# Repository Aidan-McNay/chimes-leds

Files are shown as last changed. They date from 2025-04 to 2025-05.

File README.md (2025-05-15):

# chimes-leds
A system for controlling McGraw Tower's clock face LEDs

## Documentation

Documentation for our system is located [here](https://aidan-mcnay.github.io/chimes-leds/)

Our documentation is built using Sphinx, and is
formatted as [reStructured Text](https://www.sphinx-doc.org/en/master/usage/restructuredtext/basics.html).
To build the documentation locally, first install Sphinx,
as well as our additional Sphinx modules:

```bash
pip install sphinx sphinx_rtd_theme sphinxcontrib-youtube
```

Then, you can build the output files in a `build`
directory with Sphinx, with the top-level HTML
located at `build/index.html`

```bash
sphinx-build docs build
```

This process is automated to update the Github page
on a push

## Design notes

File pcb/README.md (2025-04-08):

# pcb

A collection of the PCB files for:

 - The control panel
 - The sensor board
 - A clock face board

All of these were created with KiCad

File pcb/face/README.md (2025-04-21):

# face

The PCB files for the control board at the playing stand level

## GPIO Mapping

**LED PWM GPIOs (high for on)**:
 - **28**: Red LED
 - **26**: Green LED
 - **20**: Blue LED
 - **18**: White LED

**Status LEDs**:
 - **21**: "On" LED (high when enabled)
 - **19**: Communication LED (On when connected to control panel)

**CAN connections**:
 - **16**: CAN TX
 - **17**: CAN RX
 - **22**: CAN Enable (active low)

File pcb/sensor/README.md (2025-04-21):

# sensor

The PCB files for the control board at the playing stand level

## GPIO Mapping

**Microphone**:
 - **26**: Microphone ADC input

**Ambient Light**:
 - **21**: SCL
 - **20**: SDA
 - **19**: Interrupt (if desired)

**CAN connections**:
 - **16**: CAN TX
 - **17**: CAN RX
 - **22**: CAN Enable (active low)

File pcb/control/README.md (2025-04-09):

# control

The PCB files for the control board at the playing stand level

## GPIO Mapping

**System Configuration**:
 - **4**: System enable (whether to be on)
 - **5**: WiFi enable (whether to use WiFi configs)

**User Mode**:
 - **7**: "Light" mode (based on ambient light, set as pull-down)
 - **8**: "Music" mode (pulse with music, set as pull-down)
 - **9**: "On" mode (always on, set as pull-down)

**Color Potentiometer Inputs**
 - **28**: Red Potentiometer
 - **27**: Green Potentiometer
 - **26**: Blue Potentiometer

**Status LEDs**:
 - **10**: "On" LED (high when enabled)
 - **11**: Red LED (PWM for current color)
 - **12**: Green LED (PWM for current color)
 - **14**: Blue LED (PWM for current color)
 - **15**: WiFi LED (indicate where configs are from)

**Communication LEDs** *(whether we're communicating with a board)*:
 - **3**: Sensor Board
 - **21**: North Face
 - **20**: South Face
 - **19**: East Face
 - **18**: West Face

**CAN connections**:
 - **16**: CAN TX
 - **17**: CAN RX
 - **22**: CAN Enable (active low)

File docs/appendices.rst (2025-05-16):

Appendices
==========================================================================

Appendix A: Permissions
--------------------------------------------------------------------------

* The group approves this report for inclusion on the course website.
* The group approves the video for inclusion on the course YouTube channel.

Appendix B: Source Files
--------------------------------------------------------------------------

An up-to-date listing of our source files can always be found on the
group's `public repository <https://github.com/Aidan-McNay/chimes-leds>`_.
The most recent commit of the repository is additionally included as a
ZIP file below for completeness:

:download:`Download Source Files <files/sources.zip>`

Appendix C: Hardware Designs
--------------------------------------------------------------------------

The group used `KiCad <https://www.kicad.org/>`_ for their PCB design,
with external component symbols/footprints included as necessary from
Digikey's CAD Models (included on the part's page). All of
the design files can be found in the ``pcb`` directory of the source code,
with the schematics of the 3 PCB designs included as PDFs below:

:download:`Control Board Schematic <files/control_schematic.pdf>`

:download:`Sensor Board Schematic <files/sensor_schematic.pdf>`

:download:`Face Board Schematic <files/face_schematic.pdf>`

In addition, a CSV of our Bill of Materials (BOM) can be found here,
with Digikey part numbers and designators on the boards (noting that
the quantities provided are for one face board, but the system uses
four)

:download:`Bill of Materials <files/bom.csv>`

Appendix D: References
--------------------------------------------------------------------------

* Adafruit's wiring guide for their `RGBW LED strip <https://www.adafruit.com/product/2439>`_
  (visually very similar to ours) was used for additional confirmation that
  our understanding of the strips was correct (along with our own testing).
* While all part datasheets were used, the
  `CAN transceiver datasheet <https://www.ti.com/lit/ds/symlink/sn65hvd230.pdf>`_
  in particular proved invaluable by providing different considerations for
  CAN bus implementations, as well as an optimized example layout which
  was followed for all boards.

Appendix E: Member Responsibilities
--------------------------------------------------------------------------

* **Aidan**:

  * CMake build system setup
  * Complete hardware/PCB design, bringup, and debugging
  * Small help with utility class implementations

* **Qingmiao**:

  * Implement CAN bus working on one Pico and one CAN transceiver
  * Small help with utility class implementations

* **Edmund**:

  * Implement software interfaces to the various hardware peripherals,
    including LEDs, potentiometers, and LED-driving MOSFETs
  * Implement the top-level programs for all boards
  * Implement the CAN packet protocol to communicate across boards,
    as well as debug CAN issues

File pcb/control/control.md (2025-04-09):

# control

The PCB files for the control board at the playing stand level

## GPIO Mapping

 - **4**: System Enable
 - **4**: WiFi Enable
 - **7**: "Light" mode (set as pull-down)
 - **8**: "Music" mode (set as pull-down)
 - **9**: "On" mode (set as pull-down)
 - **10**: "On" LED (on when powered)
 - **11**: Red LED (PWM for current color)
 - **12**: Green LED (PWM for current color)
 - **14**: Blue LED (PWM for current color)
 - **15**: WiFi LED (indicate where configs are from)
 - **16**: CAN TX
 - **17**: CAN RX
 - **22**: CAN Enable (active low)
 - **26**: Red Potentiometer
 - **27**: Green Potentiometer
 - **28**: Blue Potentiometer

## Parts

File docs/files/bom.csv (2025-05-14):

Board | Designator | Quantity | Component | Manufacturer ID | Digikey Number
Control | C1 | 1 | 4.7uF | CL10A475KP8NNNC | 1276-1044-1-ND
Control | C2 | 1 | 10uF | CL10A106KQ8NNNC | 1276-1038-1-ND
Control | C3 | 1 | 100nF | CC0603KRX7R7BB104 | 311-1088-1-ND
Control | CR1 | 1 | PESD1CAN_215 | PESD1CANVL | 1727-PESD1CANVLCT-ND
Control | D1,D2,D3,D6,D7,D8,D9,D10 | 8 | LED (R) | XZCM2CRK53WA-8VF | 1497-XZCM2CRK53WA-8VFCT-ND
Control | D4 | 1 | LED (G) | XZCDGK53W-8VF | 1497-XZCDGK53W-8VFCT-ND
Control | D5 | 1 | LED (B) | XZCFBB53W-8VF | 1497-XZCFBB53W-8VFCT-ND
Control | J1 | 1 | Barrel Jack | PJ-102AH | CP-102AH-ND
Control | J2 | 1 | Screw Terminal (1x10) | 1729092 | 277-1244-ND
Control | R1,R2 | 2 | 60Ω | CRCW120660R0KNEAIF | 541-CRCW120660R0KNEAIFCT-ND
Control | R3 | 1 | 10KΩ | RES 10K OHM 1% 1/10W 0603 | 311-10.0KHRCT-ND
Control | R4 | 1 | 100KΩ | ERJ-3EKF1003V | P100KHCT-ND
Control | R5,R6,R7 | 3 | PTA4543 | PTA4543-2015DPA103 | PTA4543-2015DPA103-ND
Control | R8,R9,R10,R13,R14,R15,R16,R17 | 8 | 750Ω | RMCF1206JT750R | RMCF1206JT750RCT-ND
Control | R11,R12 | 2 | 325Ω | ERA-3AEB331V | P330DBCT-ND
Control | S1 | 1 | Rotary Switch | RM103772BCB | CKN10697-ND
Control | SW1,SW2 | 2 | Slide Switch | OS102011MS2QN1 | CKN9565-ND
Control | U1 | 1 | PicoW | SC0918 | 2648-SC0918CT-ND
Control | U2 | 1 | SN65HVD230DR | SN65HVD230DR | 296-11654-1-ND
Control | U3 | 1 | FDN340P | FDN340P | 4518-FDN340PCT-ND
Control | U4 | 1 | DMG2305UX-7 | DMG2305UX-7 | DMG2305UX-7DICT-ND
Face | C1 | 1 | 4.7uF | CL10A475KP8NNNC | 1276-1044-1-ND
Face | C2 | 1 | 10uF | CL10A106KQ8NNNC | 1276-1038-1-ND
Face | C3 | 1 | 100nF | CC0603KRX7R7BB104 | 311-1088-1-ND
Face | C4,C5 | 2 | 4.7uF | CL10A475KP8NNNC | 1276-1044-1-ND
Face | CR1 | 1 | PESD1CAN_215 | PESD1CANVL | 1727-PESD1CANVLCT-ND
Face | D1,D2 | 2 | LED (THT) | 151051RS11000 | 732-5016-ND
Face | J1 | 1 | Screw Terminal (1x2) | 1935161 | 277-1667-ND
Face | J2,J3 | 2 | Screw Terminal (1x5) | 1935190 | 277-1580-ND
Face | J4 | 1 | Big Screw Terminal (1x2) | 282856-2 | A98355-ND
Face | Q1,Q2,Q5,Q6 | 4 | Beefy NFet | IRLB8721PBF | IRLB8721PBF-ND
Face | R1,R2 | 2 | 60Ω | CRCW120660R0KNEAIF | 541-CRCW120660R0KNEAIFCT-ND
Face | R3 | 1 | 100KΩ | ERJ-3EKF1003V | P100KHCT-ND
Face | R4 | 1 | 10KΩ | RES 10K OHM 1% 1/10W 0603 | 311-10.0KHRCT-ND
Face | R5,R6 | 2 | 240Ω | ERJ-3EKF2400V | P240HCT-ND
Face | U1 | 1 | SN65HVD230DR | SN65HVD230DR | 296-11654-1-ND
Face | U2 | 1 | PicoW | SC0918 | 2648-SC0918CT-ND
Face | U3 | 1 | FDN340P | FDN340P | 4518-FDN340PCT-ND
Face | U5 | 1 | DMG2305UX-7 | DMG2305UX-7 | DMG2305UX-7DICT-ND
Face | U6 | 1 | 5V Converter | NCP1117ST50T3G | NCP1117ST50T3GOSCT-ND
Sensor | C1 | 1 | 4.7uF | CL10A475KP8NNNC | 1276-1044-1-ND
Sensor | C2 | 1 | 10uF | CL10A106KQ8NNNC | 1276-1038-1-ND
Sensor | C3 | 1 | 100nF | CC0603KRX7R7BB104 | 311-1088-1-ND
Sensor | CR1 | 1 | PESD1CAN_215 | PESD1CANVL | 1727-PESD1CANVLCT-ND
Sensor | J1 | 1 | 3-pin female header (microphone) | PPTC031LFBN-RC | S7001-ND
Sensor | J2 | 1 | Barrel Jack | PJ-102AH | CP-102AH-ND
Sensor | J3 | 1 | Screw Terminal (1x2) | 1935161 | 277-1667-ND
Sensor | R1,R2 | 2 | 60Ω | CRCW120660R0KNEAIF | 541-CRCW120660R0KNEAIFCT-ND
Sensor | R3 | 1 | 100KΩ | ERJ-3EKF1003V | P100KHCT-ND
Sensor | R4,R7 | 2 | 10KΩ | RES 10K OHM 1% 1/10W 0603 | 311-10.0KHRCT-ND
Sensor | R5,R6 | 2 | 4.7KΩ | RC0603FR-074K7L | 311-4.70KHRCT-ND
Sensor | U1 | 1 | SN65HVD230DR | SN65HVD230DR | 296-11654-1-ND
Sensor | U2 | 1 | FDN340P | FDN340P | 4518-FDN340PCT-ND
Sensor | U3 | 1 | PicoW | SC0918 | 2648-SC0918CT-ND
Sensor | U4 | 1 | Ambient Light | VEML6030-GS15 | VEML6030-GS15CT-ND
Sensor | U5 | 1 | DMG2305UX-7 | DMG2305UX-7 | DMG2305UX-7DICT-ND

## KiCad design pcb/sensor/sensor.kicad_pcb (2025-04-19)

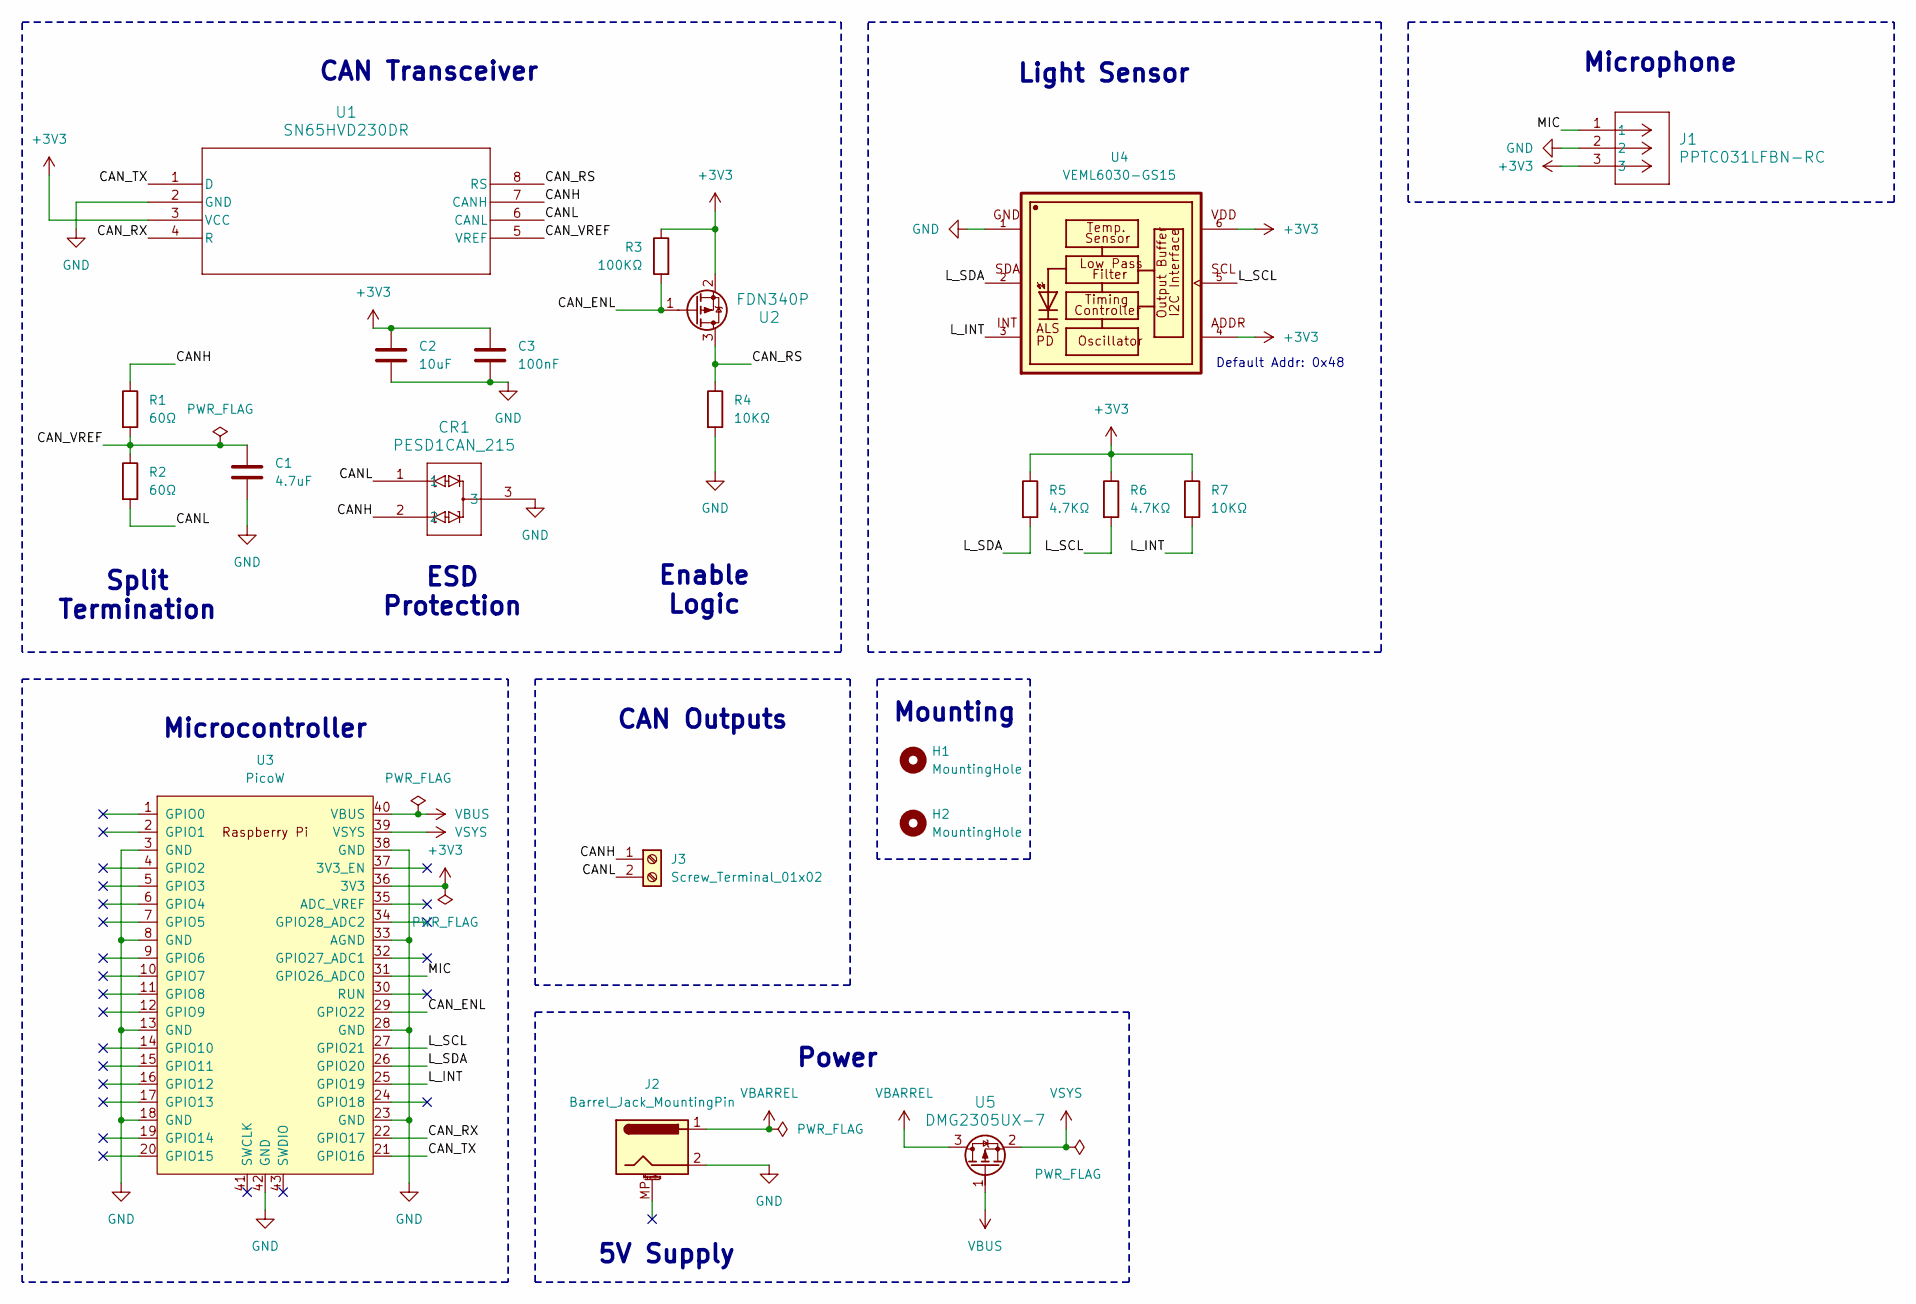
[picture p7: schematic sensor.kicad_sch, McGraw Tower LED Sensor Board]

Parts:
C1: 4.7uF; C_0603_1608Metric
C2: 10uF; C_0603_1608Metric
C3: 100nF; C_0603_1608Metric
CR1: PESD1CAN_215; SOT23_PESD1_NEX
H1, H2: MountingHole; MountingHole_3.2mm_M3_DIN965_Pad
J1: PPTC031LFBN-RC; CONN_PPTC031_SUL
J2: Barrel_Jack_MountingPin; BarrelJack_CUI_PJ-102AH_Horizontal
J3: Screw_Terminal_01x02; TerminalBlock_Phoenix_PT-1,5-2-5.0-H_1x02_P5.00mm_Horizontal
R1, R2: 60Ω; R_1206_3216Metric
R3: 100KΩ; R_0603_1608Metric
R4, R7: 10KΩ; R_0603_1608Metric
R5, R6: 4.7KΩ; R_0603_1608Metric
U1: SN65HVD230DR; D8
U2: FDN340P; SOT-23_ONS
U3: PicoW; RPi_PicoW_SMD_TH
U4: VEML6030-GS15; VISHAY_VEML6030_2X2X0.87
U5: DMG2305UX-7; SOT-23_DIO

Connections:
+3V3: C2.1, C3.1, J1.3, R3.1, R5.1, R6.1, R7.1, U1.3 (VCC), U2.2, U3.36 (3V3), U4.4, U4.6
/CANH: CR1.2, J3.1, R1.1, U1.7 (CANH)
/CANL: CR1.1, J3.2, R2.2, U1.6 (CANL)
/CAN_ENL: R3.2, U2.1, U3.29 (GPIO22)
/CAN_RS: R4.1, U1.8 (RS), U2.3
/CAN_RX: U1.4 (R), U3.22 (GPIO17)
/CAN_TX: U1.1 (D), U3.21 (GPIO16)
/CAN_VREF: C1.1, R1.2, R2.1, U1.5 (VREF)
/L_INT: R7.2, U3.25 (GPIO19), U4.3
/L_SCL: R6.2, U3.27 (GPIO21), U4.5
/L_SDA: R5.2, U3.26 (GPIO20), U4.2
/MIC: J1.1, U3.31 (GPIO26_ADC0)
GND: C1.2, C2.2, C3.2, CR1.3, J1.2, J2.2, R4.2, U1.2 (GND), U3.3 (GND), U3.8 (GND), U3.13 (GND), U3.18 (GND), U3.23 (GND), U3.28 (GND), U3.33 (AGND), U3.38 (GND), U3.42 (GND), U4.1
VBARREL: J2.1, U5.3
VBUS: U3.40 (VBUS), U5.1
VSYS: U3.39 (VSYS), U5.2

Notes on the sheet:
Microphone
CAN Outputs
Microcontroller
CAN Transceiver
Enable Logic
Power
5V Supply
Light Sensor
Mounting
ESD Protection
Split Termination
Default Addr: 0x48

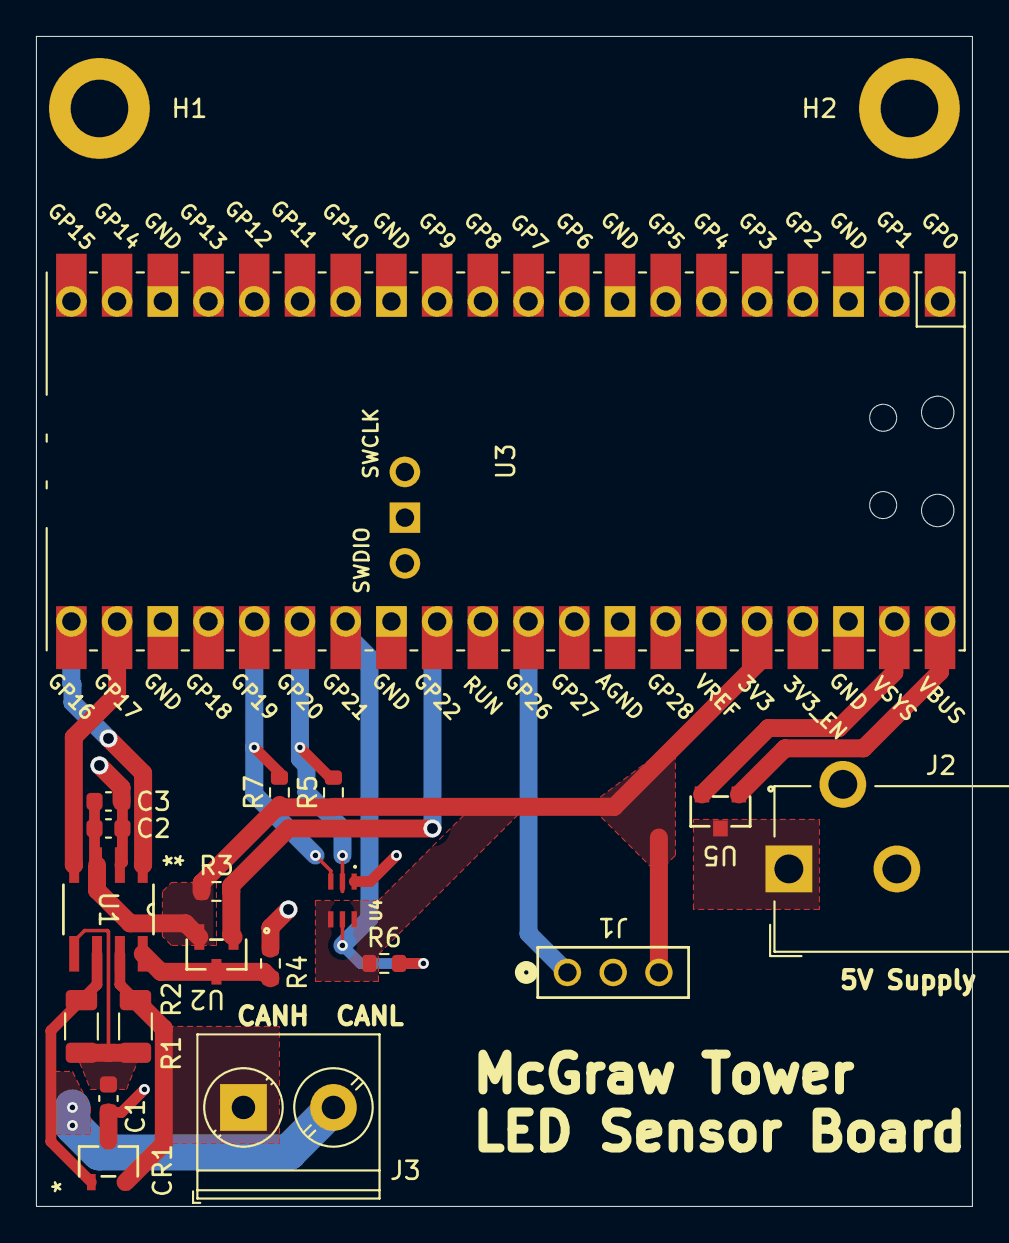
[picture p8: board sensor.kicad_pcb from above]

Board: 2 copper layers, 52.0 x 65.0 mm, 21 parts (0 on the bottom side), 16 nets.

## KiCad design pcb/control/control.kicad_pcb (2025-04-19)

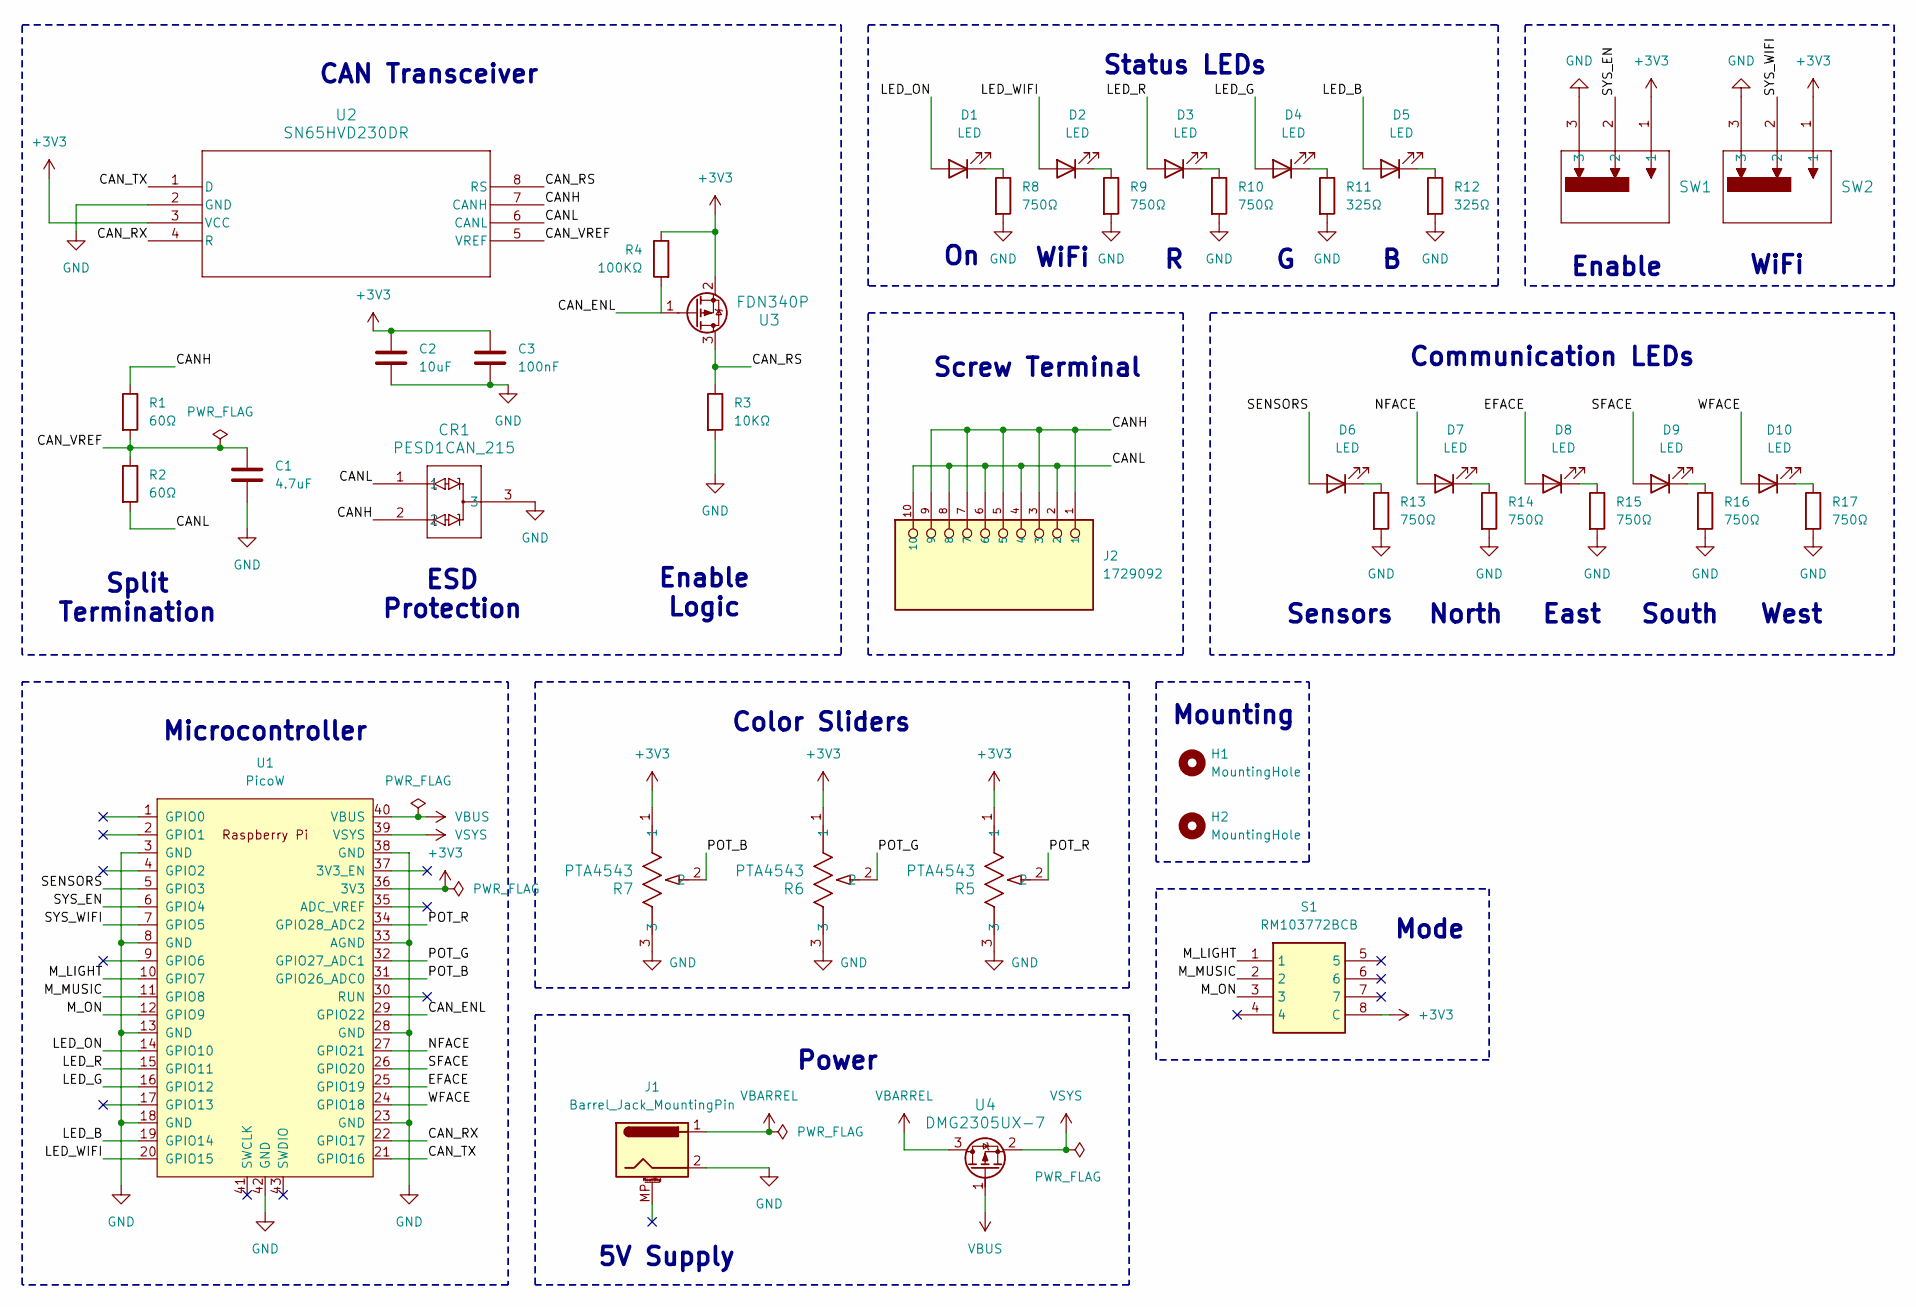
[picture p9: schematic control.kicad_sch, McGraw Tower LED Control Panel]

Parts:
C1: 4.7uF; C_0603_1608Metric
C2: 10uF; C_0603_1608Metric
C3: 100nF; C_0603_1608Metric
CR1: PESD1CAN_215; SOT23_PESD1_NEX
D1, D2, D3, D4, D5, D6, D7, D8, D9, D10: LED; LED_0603_1608Metric
H1, H2: MountingHole; MountingHole_3.2mm_M3_DIN965_Pad
J1: Barrel_Jack_MountingPin; BarrelJack_CUI_PJ-102AH_Horizontal
J2: 1729092; PHOENIX_1729092; DigiKey_Part_Number 277-1244-ND
R1, R2: 60Ω; R_1206_3216Metric
R3: 10KΩ; R_0603_1608Metric
R4: 100KΩ; R_0603_1608Metric
R5, R6, R7: PTA4543; POT_PTA4543
R8, R9, R10, R13, R14, R15, R16, R17: 750Ω; R_1206_3216Metric
R11, R12: 325Ω; R_0603_1608Metric
S1: RM103772BCB; Mouser Part Number 611-RM103772BCB
SW1, SW2: OS102011MS2QN1; SPDT_OS102011_CNK
U1: PicoW; RPi_PicoW_SMD_TH
U2: SN65HVD230DR; D8
U3: FDN340P; SOT-23_ONS
U4: DMG2305UX-7; SOT-23_DIO

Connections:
+3V3: C2.1, C3.1, R4.1, R5.1, R6.1, R7.1, S1.8 (C), SW1.1, SW2.1, U1.36 (3V3), U2.3 (VCC), U3.2
/CANH: CR1.2, J2.1, J2.3, J2.5, J2.7, J2.9, R1.1, U2.7 (CANH)
/CANL: CR1.1, J2.2, J2.4, J2.6, J2.8, J2.10, R2.2, U2.6 (CANL)
/CAN_ENL: R4.2, U1.29 (GPIO22), U3.1
/CAN_RS: R3.1, U2.8 (RS), U3.3
/CAN_RX: U1.22 (GPIO17), U2.4 (R)
/CAN_TX: U1.21 (GPIO16), U2.1 (D)
/CAN_VREF: C1.1, R1.2, R2.1, U2.5 (VREF)
/EFACE: D8.2 (A), U1.25 (GPIO19)
/LED_B: D5.2 (A), U1.19 (GPIO14)
/LED_G: D4.2 (A), U1.16 (GPIO12)
/LED_ON: D1.2 (A), U1.14 (GPIO10)
/LED_R: D3.2 (A), U1.15 (GPIO11)
/LED_WIFI: D2.2 (A), U1.20 (GPIO15)
/M_LIGHT: S1.1, U1.10 (GPIO7)
/M_MUSIC: S1.2, U1.11 (GPIO8)
/M_ON: S1.3, U1.12 (GPIO9)
/NFACE: D7.2 (A), U1.27 (GPIO21)
/POT_B: R7.2, U1.31 (GPIO26_ADC0)
/POT_G: R6.2, U1.32 (GPIO27_ADC1)
/POT_R: R5.2, U1.34 (GPIO28_ADC2)
/SENSORS: D6.2 (A), U1.5 (GPIO3)
/SFACE: D9.2 (A), U1.26 (GPIO20)
/SYS_EN: SW1.2, U1.6 (GPIO4)
/SYS_WIFI: SW2.2, U1.7 (GPIO5)
/WFACE: D10.2 (A), U1.24 (GPIO18)
GND: C1.2, C2.2, C3.2, CR1.3, J1.2, R3.2, R5.3, R6.3, R7.3, R8.2, R9.2, R10.2, R11.2, R12.2, R13.2, R14.2, R15.2, R16.2, R17.2, SW1.3, SW2.3, U1.3 (GND), U1.8 (GND), U1.13 (GND), U1.18 (GND), U1.23 (GND), U1.28 (GND), U1.33 (AGND), U1.38 (GND), U1.42 (GND), U2.2 (GND)
unnamed: D1.1 (K), R8.1
unnamed: D2.1 (K), R9.1
unnamed: D3.1 (K), R10.1
unnamed: D4.1 (K), R11.1
unnamed: D5.1 (K), R12.1
unnamed: D6.1 (K), R13.1
unnamed: D7.1 (K), R14.1
unnamed: D8.1 (K), R15.1
unnamed: D9.1 (K), R16.1
unnamed: D10.1 (K), R17.1
VBARREL: J1.1, U4.3
VBUS: U1.40 (VBUS), U4.1
VSYS: U1.39 (VSYS), U4.2

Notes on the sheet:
WiFi
Sensors
Status LEDs
5V Supply
Split Termination
Power
Mode
South
Color Sliders
Communication LEDs
Enable Logic
East
Enable
Screw Terminal
Microcontroller
CAN Transceiver
ESD Protection
North
Mounting
West

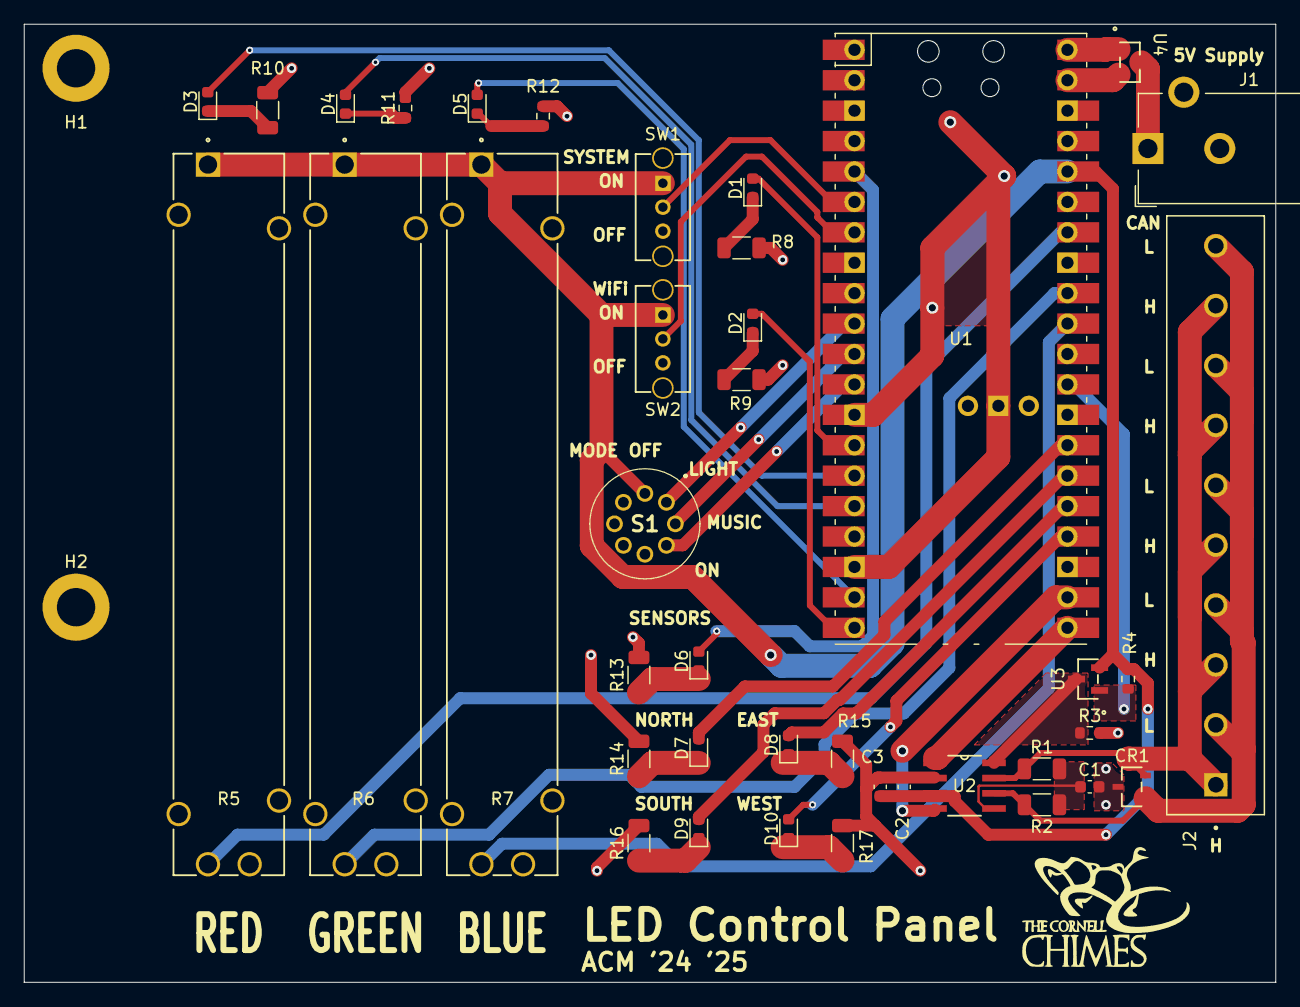
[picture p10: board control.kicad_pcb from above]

Board: 2 copper layers, 104.5 x 80.0 mm, 42 parts (0 on the bottom side), 40 nets.

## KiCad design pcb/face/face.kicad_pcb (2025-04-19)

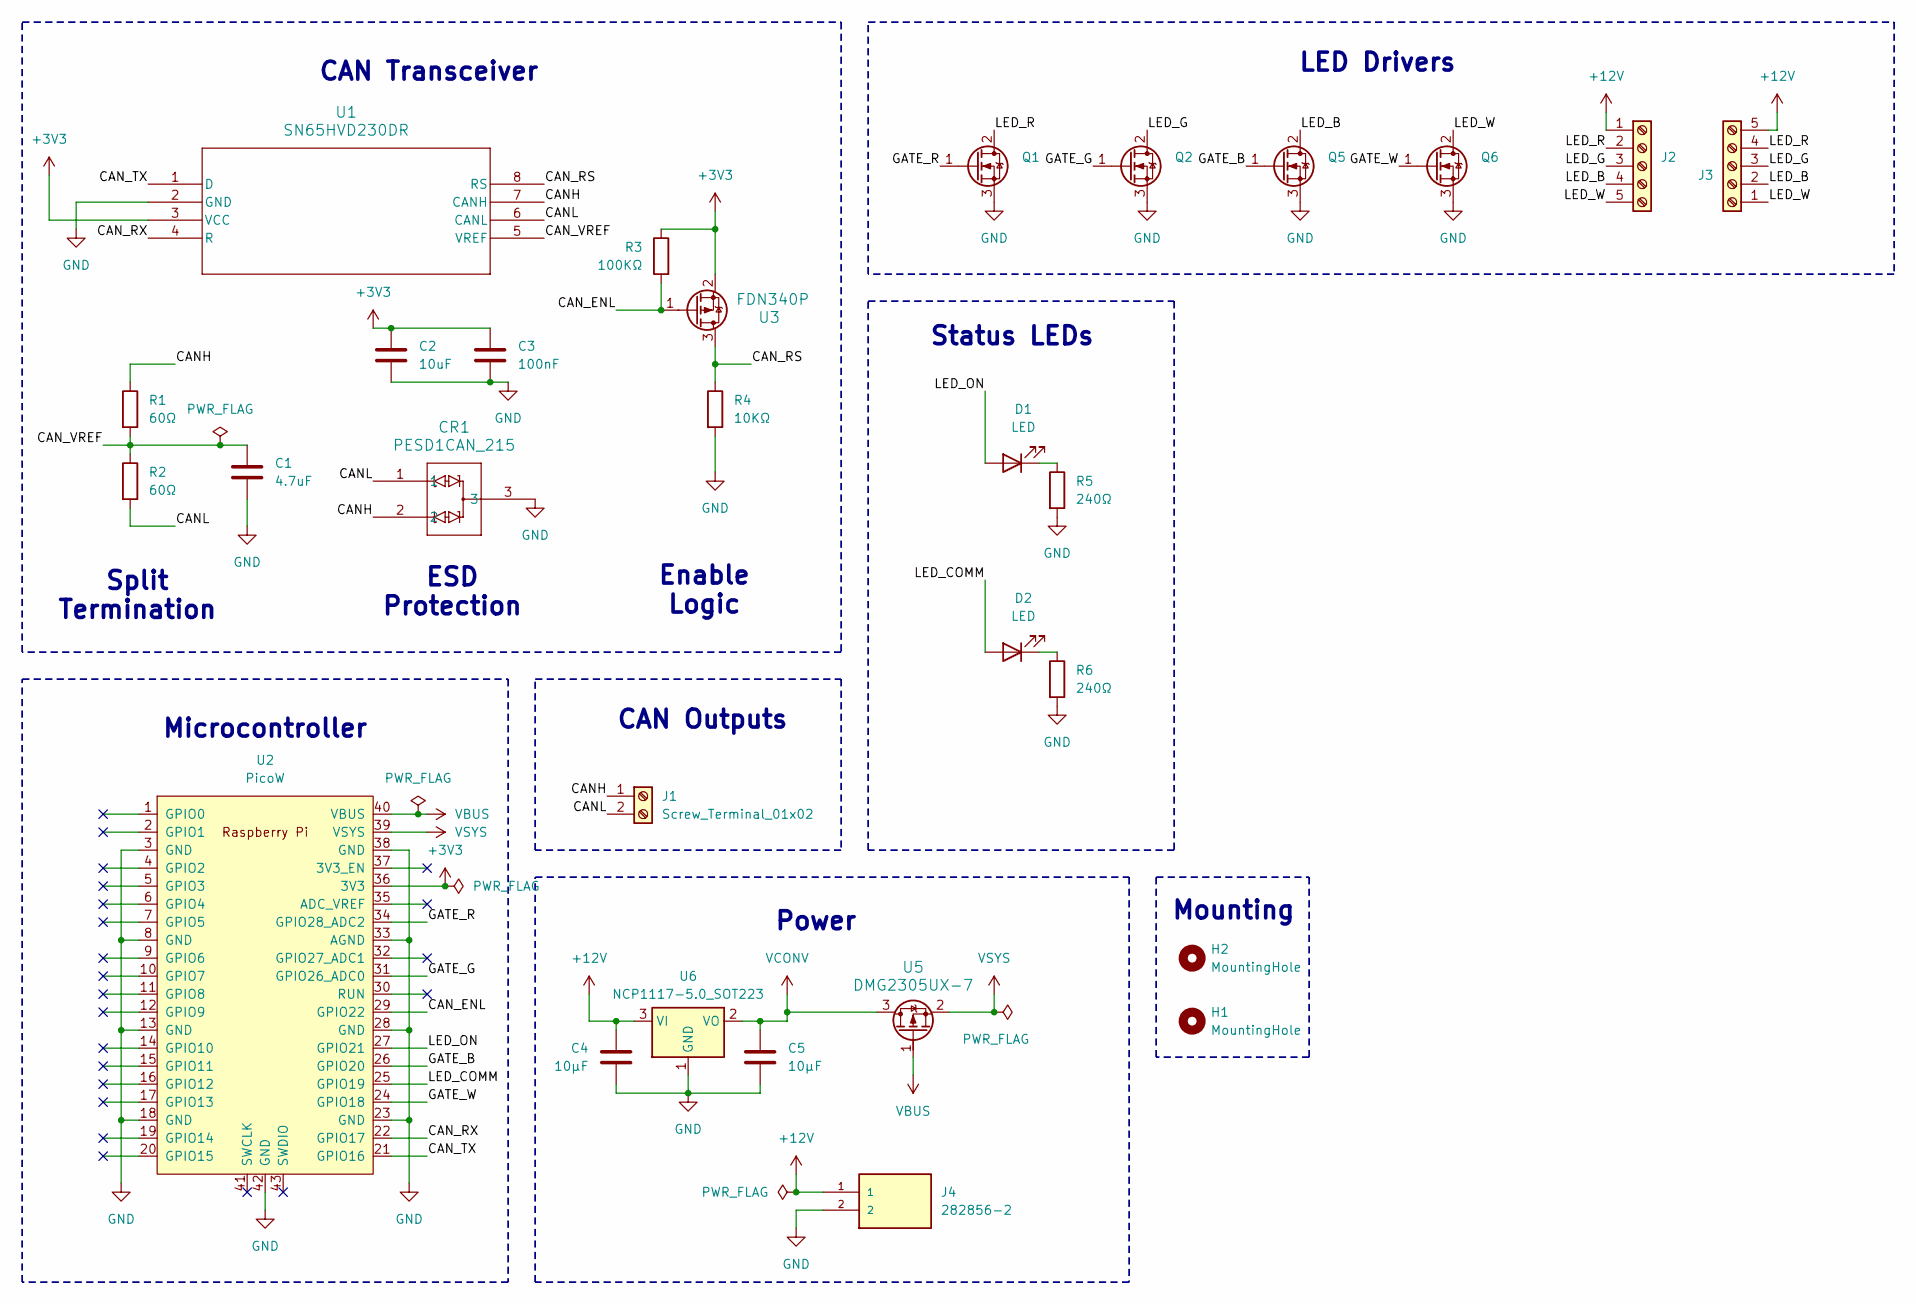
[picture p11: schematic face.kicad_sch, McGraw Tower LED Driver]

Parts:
C1: 4.7uF; C_0603_1608Metric
C2: 10uF; C_0603_1608Metric
C3: 100nF; C_0603_1608Metric
C4, C5: 10μF; C_0603_1608Metric
CR1: PESD1CAN_215; SOT23_PESD1_NEX
D1, D2: LED; LED_D5.0mm
H1, H2: MountingHole; MountingHole_3.2mm_M3_DIN965_Pad
J1: Screw_Terminal_01x02; TerminalBlock_Phoenix_PT-1,5-2-5.0-H_1x02_P5.00mm_Horizontal
J2, J3: Screw_Terminal_01x05; TerminalBlock_Phoenix_PT-1,5-5-5.0-H_1x05_P5.00mm_Horizontal
J4: 282856-2; TE_282856-2; PARTREV R
Q1, Q2, Q5, Q6: IRLB8721PBF; TO-220-3_Vertical
R1, R2: 60Ω; R_1206_3216Metric
R3: 100KΩ; R_0603_1608Metric
R4: 10KΩ; R_0603_1608Metric
R5, R6: 240Ω; R_0603_1608Metric
U1: SN65HVD230DR; D8
U2: PicoW; RPi_PicoW_SMD_TH
U3: FDN340P; SOT-23_ONS
U5: DMG2305UX-7; SOT-23_DIO
U6: NCP1117-5.0_SOT223; SOT-223-3_TabPin2

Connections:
+3V3: C2.1, C3.1, R3.1, U1.3 (VCC), U2.36 (3V3), U3.2
+12V: C4.1, J2.1, J3.5, J4.1, U6.3 (VI)
/CANH: CR1.2, J1.1, R1.1, U1.7 (CANH)
/CANL: CR1.1, J1.2, R2.2, U1.6 (CANL)
/CAN_ENL: R3.2, U2.29 (GPIO22), U3.1
/CAN_RS: R4.1, U1.8 (RS), U3.3
/CAN_RX: U1.4 (R), U2.22 (GPIO17)
/CAN_TX: U1.1 (D), U2.21 (GPIO16)
/CAN_VREF: C1.1, R1.2, R2.1, U1.5 (VREF)
/GATE_B: Q5.1 (G), U2.26 (GPIO20)
/GATE_G: Q2.1 (G), U2.31 (GPIO26_ADC0)
/GATE_R: Q1.1 (G), U2.34 (GPIO28_ADC2)
/GATE_W: Q6.1 (G), U2.24 (GPIO18)
/LED_B: J2.4, J3.2, Q5.2 (D)
/LED_COMM: D2.2 (A), U2.25 (GPIO19)
/LED_G: J2.3, J3.3, Q2.2 (D)
/LED_ON: D1.2 (A), U2.27 (GPIO21)
/LED_R: J2.2, J3.4, Q1.2 (D)
/LED_W: J2.5, J3.1, Q6.2 (D)
GND: C1.2, C2.2, C3.2, C4.2, C5.2, CR1.3, J4.2, Q1.3 (S), Q2.3 (S), Q5.3 (S), Q6.3 (S), R4.2, R5.2, R6.2, U1.2 (GND), U2.3 (GND), U2.8 (GND), U2.13 (GND), U2.18 (GND), U2.23 (GND), U2.28 (GND), U2.33 (AGND), U2.38 (GND), U2.42 (GND), U6.1 (GND)
unnamed: D1.1 (K), R5.1
unnamed: D2.1 (K), R6.1
VBUS: U2.40 (VBUS), U5.1
VCONV: C5.1, U5.3, U6.2 (VO)
VSYS: U2.39 (VSYS), U5.2

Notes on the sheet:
LED Drivers
Status LEDs
Microcontroller
CAN Transceiver
Mounting
CAN Outputs
Enable Logic
Split Termination
ESD Protection
Power

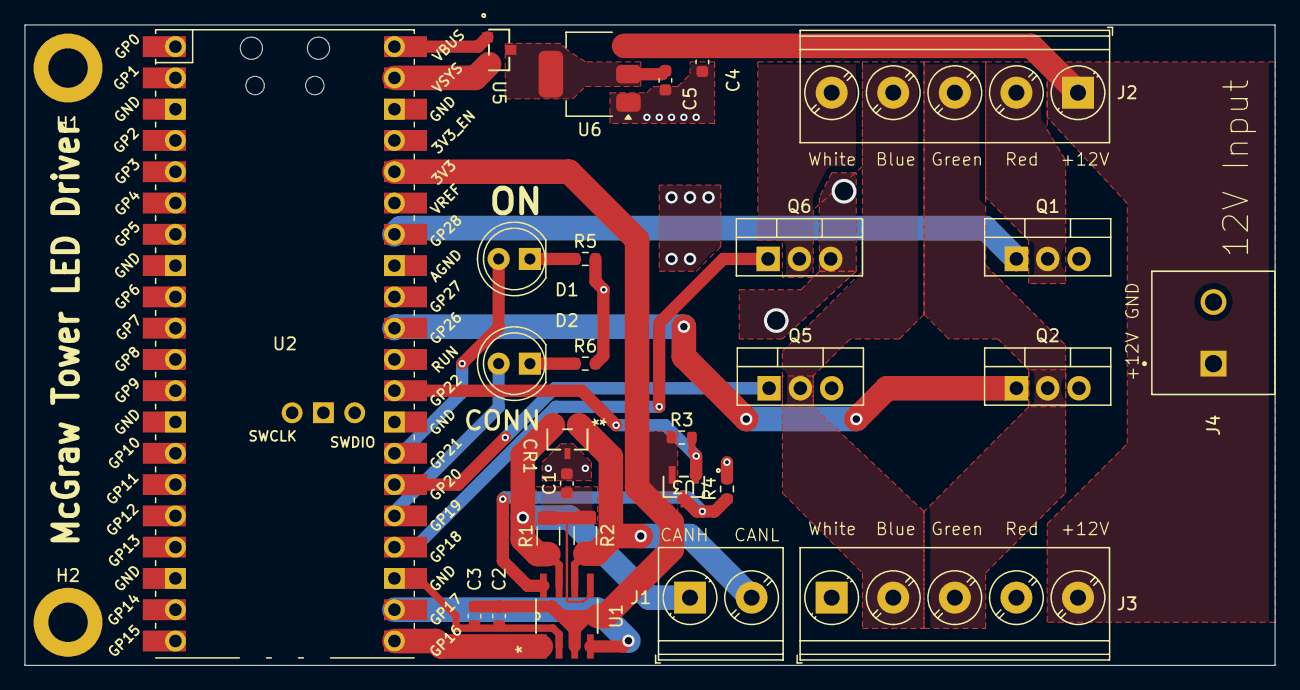
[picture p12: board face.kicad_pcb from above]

Board: 2 copper layers, 101.5 x 52.0 mm, 29 parts (0 on the bottom side), 25 nets.

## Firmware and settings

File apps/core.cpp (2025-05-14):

// Standard C libraries
#include <stdio.h>
#include <string.h>
#include <stdlib.h>
// High-level pico libraries
#include "pico/stdlib.h"
#include "pico/multicore.h"
// Interface library to sys_clock (SDK 2.0.0 )
#include "hardware/clocks.h"
// CAN driver
#include "can/can.h"
// Protothreads
#include "utils/pt_cornell_rp2040_v1.h"
#include "utils/can_interface.h"
#include "utils/state.h"
#include "interface/switch.h"
#include "interface/color_adc.h"
#include "interface/led.h"
#include "interface/pwm.h"
#include "can/can.h"
#include "interface/pico_led.h"
#include "utils/fix15.h"

State core_state = State();

CAN can_bus( CORE_ARBITRATION, NETWORK_BROADCAST, 16, 22);

Switch system_enable(4); // whether to be on
Switch wifi_enable(5);   // whether to use WiFi configs
Switch light_mode(7);
Switch music_mode(8);
Switch on_mode(9);

ColorInput color_in;

LED is_on(10);
PWM red_out(11, 125.0f, 255, 0);
PWM green_out(12, 125.0f, 255, 0);
PWM blue_out(14, 125.0f, 255, 0);
LED wifi_on(15);

void on_color_update(State *s) {
  color_rgb c = s->get_led_color().get_rgb();

  printf("Setting color to %d %d %d\n", c.red, c.green, c.blue);

  red_out.set_duty(c.red);
  green_out.set_duty(c.green);
  blue_out.set_duty(c.blue);

  unsigned short payload[4];

  payload[0] = SET_COLOR;
  payload[1] = c.red;
  payload[2] = c.green;
  payload[3] = c.blue;

  can_bus.set_payload(payload, 4);

  can_bus.set_arbitration(CLOCK_FACE_ARBITRATION[0]);
  can_bus.sendPacket();

  // for (short clock_face : CLOCK_FACE_ARBITRATION) {
  //   can_bus.set_arbitration(clock_face);
  //   can_bus.sendPacket();
  // }
}

void on_led_update(State *s) {
  bool on = s->get_led_on();

  unsigned short payload[2];

  payload[0] = SET_TOGGLE;
  payload[1] = on;
  can_bus.set_payload(payload, 2);

  for (short clock_face : CLOCK_FACE_ARBITRATION) {
    can_bus.set_arbitration(clock_face);
    can_bus.sendPacket();
  }
}

void on_mode_change(State *s) {
      unsigned short payload[1];
  switch (s->get_led_mode()) {
    case LIGHT:
      // Send light mode to light sensor
      payload[0] = SENSOR_LIGHT;
      break;
    case MUSIC:
      // Send music mode to sound sensor
      payload[0] = SENSOR_SOUND;
      break;
    case CONST:
      // Send const mode to clock face
      payload[0] = SET_TOGGLE;
      break;
  }
  
  can_bus.set_payload(payload, 1);
  can_bus.set_arbitration(SENSOR_ARBITRATION);
  can_bus.sendPacket();

  // If the mode is set to const, turn on the LED
  if (s->get_led_mode() == CONST) {
    s->set_led_on(true);
  }

  // Otherwise, this will be handled elsewhere
}

// Read sensor data
fix15 last_light;
fix15 last_sound;

#define DECIBEL_MAX int2fix15(100)
#define DECIBEL_MIN int2fix15(0)

void read_packet( const unsigned short* packet, const unsigned char len ) {
  switch (packet[0]) {
    case SENSOR_LIGHT:
      // Right the light sensor data
      if (len != 3) {
        printf("Error: light packet length %d\n", len);
        return;
      }

      last_light = (packet[1] << 16) + packet[2];
      break;

    case SENSOR_SOUND:
      // Right the sound sensor data
      if (len != 3) {
        printf("Error: sound packet length %d\n", len);
        return;
      }

      last_sound = (packet[1] << 16) + packet[2];
      printf("Received sound data %f\n", fix2float15(last_sound));
      break;
    default:
      // Nothing to do here
      break;
  }
}

// us per sample
#define PARAM_SAMPLE_RATE 10000

// Lux cap for light sensor below which to turn on LEDs
#define LUX_CAP int2fix15(1)

static PT_THREAD( protothread_core( struct pt *pt ) )
{
  PT_BEGIN( pt );
  static int begin_time, elapsed_time;

  while (1) {
    // Measure time at start of thread
    begin_time = time_us_32();
    
    is_on.toggle(system_enable.enabled());
    wifi_on.toggle(wifi_enable.enabled());

    if (system_enable.enabled()) {

      if (light_mode.enabled()) {
        core_state.set_led_mode(LIGHT);
      } else if (music_mode.enabled()) {
        core_state.set_led_mode(MUSIC);
      } else if (on_mode.enabled()) {
        core_state.set_led_mode(CONST);
      } else {
        printf("No modes selected.\n");
      }

      printf("Running in mode %d\n", core_state.get_led_mode());

      color_rgb c = color_in.sample();
      
      switch (core_state.get_led_mode()) {
        case LIGHT:
          // Send light sensor data to watch faces
          if (last_light > LUX_CAP) {
            // Set the color to the light sensor value
            core_state.set_led_on(true);
          } else {
            // Turn off the LEDs
            core_state.set_led_on(false);
          }
          break;
        case MUSIC:
          core_state.set_led_on(true);
          printf("Current volume %f\n", fix2float15(last_sound));

        
          // Set brightness based on volume
          c.red = (uint8_t) ((float) c.red * fix2float15(last_sound));
          c.green = (uint8_t) ((float) c.green * fix2float15(last_sound));
          c.blue = (uint8_t) ((float) c.blue * fix2float15(last_sound));

          break;
        case CONST:
          
          core_state.set_led_on(true);
          // Handle manual mode
          // Read red, green, and blue in values and set the color
          break;
      }
      
      core_state.set_led_color(Color(c));
    } else {
      // If the system is not enabled, turn off the LEDs
      core_state.set_led_on(false);
      printf("System disabled\n");
    }
  

    elapsed_time = time_us_32() - begin_time;

    // yield for necessary amount of time
    PT_YIELD_usec( PARAM_SAMPLE_RATE - elapsed_time );
  }
  PT_END( pt );
}

//                        USER INTERRUPT SERVICE ROUTINES
//
// ISR entered at the end of packet transmit.
void tx_handler() {
  can_bus.handle_tx() ;
}
// ISR entered when a packet is available for attempted receipt.
void rx_handler() {
  can_bus.handle_rx() ;
}

//                             MAIN FOR CORES 0 AND 1
//
// Main for core 1
void core1_main() {
    // CAN transmitter will run on core 1
    can_bus.setupCANTX(tx_handler) ;

    printf("TX handler set up\n");
    
    pt_add_thread( protothread_core );

    // Start the threader
    pt_schedule_start ;
}

// Main for core 0
int main() {
  // Overclock to 160MHz (divides evenly to 1 megabaud) (160/5/32=1)
  set_sys_clock_khz(OVERCLOCK_RATE, true) ;

  // Initialize stdio
  stdio_init_all();
  sleep_ms(5000);

  printf("Launching...\n");

  // Initialize state callbacks
  core_state.add_led_on_callback( on_led_update );
  core_state.add_led_mode_callback( on_mode_change );
  core_state.add_led_color_callback( on_color_update );

  red_out.toggle(true);
  green_out.toggle(true);
  blue_out.toggle(true);

  // start core 1 threads
  multicore_reset_core1();
  multicore_launch_core1(&core1_main);

  // Set can bus callback
  can_bus.set_callback( read_packet );

  // Setup the CAN receiver on core 0
  can_bus.setupCANRX(rx_handler) ;

  printf("RX handler set up\n");

  pt_schedule_start ;
}

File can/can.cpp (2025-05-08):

#include "can.pio.h"
#include "can/can.h"
#include "hardware/dma.h"
#include "hardware/pio.h"
#include "pico/stdlib.h"
#include "stdio.h"
#include <string.h>

// 2344 D506 0820 B041 0608 2082 0824 C106 FFFF

// ----------------------------------------------------------------------
// Define buffers for storing studded/unstuffed packets for TX/RX
// ----------------------------------------------------------------------

// Assembled packet for transmission (unstuffed then stuffed)
unsigned short  tx_packet_unstuffed[MAX_PACKET_LEN]       = { 0 };
unsigned short  tx_packet_stuffed[MAX_STUFFED_PACKET_LEN] = { 0 };
unsigned short* tx_packet_stuffed_pointer = &tx_packet_stuffed[0];

// Buffer for received packets (stuffed then unstuffed)
unsigned short  rx_packet_stuffed[MAX_STUFFED_PACKET_LEN] = { 0 };
unsigned short  rx_packet_unstuffed[MAX_PACKET_LEN]       = { 0 };
// unsigned char* rx_packet_stuffed_pointer = (unsigned char*) (&rx_packet_stuffed[0]);
unsigned short* rx_packet_stuffed_pointer = &rx_packet_stuffed[0];

// For re-initializing these buffers
unsigned short zero_packet[MAX_STUFFED_PACKET_LEN] = { 0 };

// ----------------------------------------------------------------------
// Define infrastructure globals
// ----------------------------------------------------------------------

// PIO blocks
PIO pio_0 = pio0;
PIO pio_1 = pio1;
// State machines
int can_tx_sm         = 0;
int can_idle_check_sm = 1;
int can_rx_sm         = 0;
// Select dma channels
int dma_chan_0 = 5;
int dma_chan_1 = 4;
int dma_chan_2 = 2;
int dma_chan_3 = 3;
// Dummy DMA source/destination for chained channel
unsigned int dummy_source = 0;
unsigned int dummy_dest   = 0;

// ----------------------------------------------------------------------
// Initialize CAN driver
// ----------------------------------------------------------------------

CAN::CAN( unsigned short my_arbitration, unsigned short network_broadcast,
          int can_tx, int transceiver_en
)
    : 
      packet_handler( NULL ),
      can_tx( can_tx ),
      transceiver_en( transceiver_en ),
      my_arbitration( my_arbitration ),
      arbitration( 0 ),
      network_broadcast( network_broadcast ),
      tx_idle_time( 500 ),
      reserve_byte( 0x55 ),
      payload_len( 10 ),
      number_sent( 0 ),
      number_received( 0 ),
      number_missed( 0 ),
      unsafe_to_tx( 1 )
{
}

// ----------------------------------------------------------------------
// Public accessor functions
// ----------------------------------------------------------------------

// ISR entered at the end of packet transmit
void CAN::handle_tx()
{
  // Abort/reset DMA channel, clear FIFO, clear PIO irq
  resetTransmitter();
  number_sent += 1;
  // Signal to thread that it is safe to transmit
  unsafe_to_tx = 0;
}

// ISR entered when a packet is available for attempted receipt
void CAN::handle_rx()
{
  // Abort/reset DMA channel
  resetReceiver();
  // Attempt packet receipt
  if ( attemptPacketReceive() ) {
    number_received += 1;

    // Call the packet handler
    if ( packet_handler ) {
      packet_handler( &rx_packet_unstuffed[2], rx_packet_unstuffed[1] & 0xFF );
    }
  }
  else {
    number_missed += 1;
  }

  // Clear the interrupt to receive the next message
  acceptNewPacket();
}

// Computes the checksum over a series of bytes
unsigned short CAN::culCalcCRC( char crcData, unsigned short crcReg )
{
  for ( int i = 0; i < 8; i++ ) {
    if ( ( ( crcReg & 0x8000 ) >> 8 ) ^ ( crcData & 0x80 ) ) {
      crcReg = ( crcReg << 1 ) ^ CRC16_POLY;
    }
    else {
      crcReg = ( crcReg << 1 );
    }
    crcData <<= 1;
  }
  return crcReg;
}

// Packet transmission
unsigned short CAN::getBitShort( unsigned short* shorty,
                                 unsigned char   bitnum )
{
  switch ( bitnum ) {
    case 0:
      return ( ( *shorty & 0x8000 ) >> 15 );
    case 1:
      return ( ( *shorty & 0x4000 ) >> 14 );
    case 2:
      return ( ( *shorty & 0x2000 ) >> 13 );
    case 3:
      return ( ( *shorty & 0x1000 ) >> 12 );
    case 4:
      return ( ( *shorty & 0x0800 ) >> 11 );
    case 5:
      return ( ( *shorty & 0x0400 ) >> 10 );
    case 6:
      return ( ( *shorty & 0x0200 ) >> 9 );
    case 7:
      return ( ( *shorty & 0x0100 ) >> 8 );
    case 8:
      return ( ( *shorty & 0x0080 ) >> 7 );
    case 9:
      return ( ( *shorty & 0x0040 ) >> 6 );
    case 10:
      return ( ( *shorty & 0x0020 ) >> 5 );
    case 11:
      return ( ( *shorty & 0x0010 ) >> 4 );
    case 12:
      return ( ( *shorty & 0x0008 ) >> 3 );
    case 13:
      return ( ( *shorty & 0x0004 ) >> 2 );
    case 14:
      return ( ( *shorty & 0x0002 ) >> 1 );
    case 15:
      return ( ( *shorty & 0x0001 ) >> 0 );
    default:
      return 0xFFFF;
  }
}

void CAN::modifyBitShort( unsigned short* shorty, unsigned char bitnum,
                          unsigned short value )
{
  switch ( bitnum ) {
    case 15:
      *shorty |= ( ( value << 0 ) & 0x0001 );
      break;
    case 14:
      *shorty |= ( ( value << 1 ) & 0x0002 );
      break;
    case 13:
      *shorty |= ( ( value << 2 ) & 0x0004 );
      break;
    case 12:
      *shorty |= ( ( value << 3 ) & 0x0008 );
      break;
    case 11:
      *shorty |= ( ( value << 4 ) & 0x0010 );
      break;
    case 10:
      *shorty |= ( ( value << 5 ) & 0x0020 );
      break;
    case 9:
      *shorty |= ( ( value << 6 ) & 0x0040 );
      break;
    case 8:
      *shorty |= ( ( value << 7 ) & 0x0080 );
      break;
    case 7:
      *shorty |= ( ( value << 8 ) & 0x0100 );
      break;
    case 6:
      *shorty |= ( ( value << 9 ) & 0x0200 );
      break;
    case 5:
      *shorty |= ( ( value << 10 ) & 0x0400 );
      break;
    case 4:
      *shorty |= ( ( value << 11 ) & 0x0800 );
      break;
    case 3:
      *shorty |= ( ( value << 12 ) & 0x1000 );
      break;
    case 2:
      *shorty |= ( ( value << 13 ) & 0x2000 );
      break;
    case 1:
      *shorty |= ( ( value << 14 ) & 0x4000 );
      break;
    case 0:
      *shorty |= ( ( value << 15 ) & 0x8000 );
      break;
    default:
      printf( "Invalid argument to modifyBitChar   \n" );
      break;
  }
}
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

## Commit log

2025-04-08 Started control PCB
    [control.kicad_pcb, control.kicad_sch]
2025-04-08 Remove KiCad backups
2025-04-09 Working on control PCB more
    [control.kicad_sch]
2025-04-09 Schematic finished, working on layout
    [control.kicad_pcb, control.kicad_sch]
2025-04-09 Update control schematic
    [control.kicad_sch]
2025-04-09 Control PCB done
    [control.kicad_pcb, control.kicad_sch]
2025-04-09 Increase power trace width
    [control.kicad_pcb]
2025-04-10 Started sensor board
    [sensor.kicad_pcb, sensor.kicad_sch]
2025-04-10 Add light sensor
2025-04-14 Worked on PCBs
    [face.kicad_pcb, face.kicad_sch, sensor.kicad_sch]
2025-04-14 Incremental PCB
    [sensor.kicad_sch]
2025-04-18 PCBs hopefully done
    [control.kicad_pcb, control.kicad_sch, face.kicad_pcb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]
2025-04-19 Final boards
    [control.kicad_pcb, control.kicad_sch, face.kicad_pcb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]
2025-04-21 Pin mapping
2025-04-23 working calibration script
2025-04-28 fixed calibration software
2025-05-02 working adc round robin
2025-05-02 reimplement CAN bus
2025-05-14 Updated appendices
    [bom.csv]
2025-05-14 control board
2025-05-14 sensor board
